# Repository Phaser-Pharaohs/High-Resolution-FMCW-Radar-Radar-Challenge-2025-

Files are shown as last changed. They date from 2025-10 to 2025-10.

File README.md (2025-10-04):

# Phaser Pharaohs – High-Resolution FMCW Radar (Radar Challenge 2025)

## Overview  
This repository contains the open-source project files from **Team Phaser Pharaohs** for the **IEEE AESS Radar Challenge 2025**.  
We modified the **Analog Devices CN0566 Phaser** platform to achieve **5 cm range resolution** for **non-destructive testing (NDT)**.  

---

## Motivation  
- provide a **non-destructive, high-resolution radar imaging tool**.  

---

## Key Achievements  
- Expanded usable radar **bandwidth from 500 MHz → 3 GHz**  
- Achieved **5 cm range resolution** and resolved **7 cm target separations**  
- Designed and fabricated custom **Horn TX** and **Vivaldi RX** antennas  
- Implemented **near-field focused beamforming** for sub-meter imaging  
- Demonstrated imaging on **sandbox rods** and **RAAC samples**  

---

## Hardware Modifications  
Full details are in [`docs/Modifications.docx`](docs/Modifications.docx).  
Summary of changes:  

- **Filters**  
  - Replaced *LFCW-1062+* with *LFCW-1142+* (TX/RX path)  
  - Removed *BFCN-1052+* on TX path  
  - Optional IF bandpass filter for SNR improvement  
- **Local Oscillator**: HMC735 VCO extended to **9.5–12.6 GHz**  
- **Antennas**  
  - **Vivaldi RX Array**  
    - Fabrication substrate: **Rogers RT/duroid 5880, 0.062” (1.575 mm)**  
    - Layout provided in **ODB++ format**  
  - **Horn TX Antennas** (12 dBi and 18 dBi)  
    - CAD models in **STL format**  
    - SMA connector: **MC002927**  
    - Inner pin length: **7 mm** inside waveguide (coax-to-waveguide transition)  
- **Routing**: RF rerouted to MMCX connectors for external antenna interfacing  

**Result:** Operation extended to **8–11 GHz** with ~5 cm resolution, optimized for high-resolution short-range imaging.  

---

## Repository Structure  
```
├── hardware/          
│   ├── horns/         # STL models for 12 dBi and 18 dBi horn antennas
│   ├── vivaldi/       # ODB++ files for Vivaldi PCB antenna
│   └── docs/          # Antenna datasheets and fabrication notes
├── software/          # Python/Matlab scripts for data acquisition & processing
├── experiments/       # Test datasets (sandbox rods, RAAC panels)
├── docs/              # Challenge documentation and presentations
│   ├── IEEE-Challenge-Flyer.pdf
│   ├── PhaserPharaohs_Presentation.pptx
│   └── Modifications.docx
└── README.md
```

---

## Installation & Usage  

### Requirements  
- CN0566 Phaser kit (modified)  
- ADALM-PLUTO SDR  
- Python ≥ 3.9 with:  
  ```
  numpy
  matplotlib
  scipy
  pyadi-iio
  ```

### Example Run  
```bash
git clone https://github.com/<your-org>/phaser-pharaohs-radar.git
cd phaser-pharaohs-radar/software

# Acquire test data
python acquire_data.py

# Process and plot results
python process_results.py
```

---

## Results  
- **Sandbox test**: resolved two rods at **7–10 cm separation**  
- **RAAC sample**: imaged hidden steel reinforcement with focused beamforming  
- Achieved **6× resolution improvement** over stock Phaser configuration  

---

## Future Work  
- 3D reconstruction using antenna array + translational motion  
- SAR/ISAR extensions for larger structures  
- Applications in **bridges, tunnels, and aerospace composites**  

---

## References  
- [Analog Devices CN0566 Phaser](https://www.analog.com/cn0566)  
- [IEEE AESS Radar Challenge 2025](https://ieee-aess.org/radar-challenge)  
- [RadarConf 2025 – Krakow](https://radarconf2025.org/)  

---

## License  
Released under the **MIT License** in accordance with the Radar Challenge open-source requirement.

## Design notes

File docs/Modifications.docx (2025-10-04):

Hardware Modifications

| No | PN | Description | Operating freq. | Notes
Tx path | 1 | AD9363 | RF Agile Transceiver | 325 MHz to 3.8 GHz
| 2 | LFCG-2500+ | Low Pass Filter | DC to 2500 MHz
| 3 | LTC5548 | Microwave Mixer | RF 2GHz to 14GHz IF DC–6GHz
| 4 | LFCW-1062+ | Low Pass Filter | DC to 10.6 GHz | Replace with LFCW-1142+
| 5 | BFCN-1052+ | LTCC Band Pass Filter | 9700 - 11950 MHz | Remove but Can be kept temporarily
| 6 | ADL8107 | Low Noise Amplifier | 6 GHz to 18 GHz
Rx path | 1 | ADL8107 | Low Noise Amplifier | 6 GHz to 18 GHz
| 2 | ADAR1000 | 4-Channel Beamformer | 8 GHz to 16 GHz
| 3 | LFCW-1062+ | Low Pass Filter | DC to 10.6 GHz | Replace with LFCW-1142+
| 4 | LTC5548 | Microwave Mixer | RF 2GHz to 14GHz IF DC–6GHz
| 5 | BFCN-1801+ | LTCC Band Pass Filter | 1400 - 2320 MHz
Local oscillator | 1 | ADF4159 | Frequency Synthesizer | 500MHz -13GHz
| 2 | HMC735 | VCO with Divide-by-4 | 10.5 - 12.2 GHz | 9.5-12.6
| 3 | HMC655 | 6 dB Passive Attenuator | DC - 50 GHz
| 4 | ADRF5019 | SPDT Switch, Nonreflective | 100 MHz to 13 GHz
| 5 | EP2C+ | 2 Ways MMIC DC Pass Power Splitter | 1800 - 12500 MHz
Antenna | 1 | | 8-element patch antenna | 10-10.5GHz | Replace with Vivaldi Array 8-11 GHz

*Tx: Replace (LFCW-1062+) with (LFCW-1142+) and remove (BFCN-1052+) then we can change the Tx frequency to be 6-14GHz.

*Rx: Replace (LFCW-1062+) with (LFCW-143+) then we can change the Rx frequency to be 8-14GHz.

*LO: The VCO operating frequency is 10.5 - 12.2 GHz, but according to the datasheet, this could be extended to be from 9.5- 12.6 GHz.

*Antenna: The patch antenna array has a limited bandwidth. We can replace it with wider bandwidth elements, such as Vivaldi. The routing should be modified to the mmcx connectors instead of the patch antennas.

After the modifications, the radar could operate between 8-11 GHz with a 1.5 GHz IF frequency, offering good range resolution. Applications that require high resolution.

To enhance the SNR, another BPF centred at the IF frequency could be added between the radar board (CN0566) and the ADALM-PLUTO SDR.

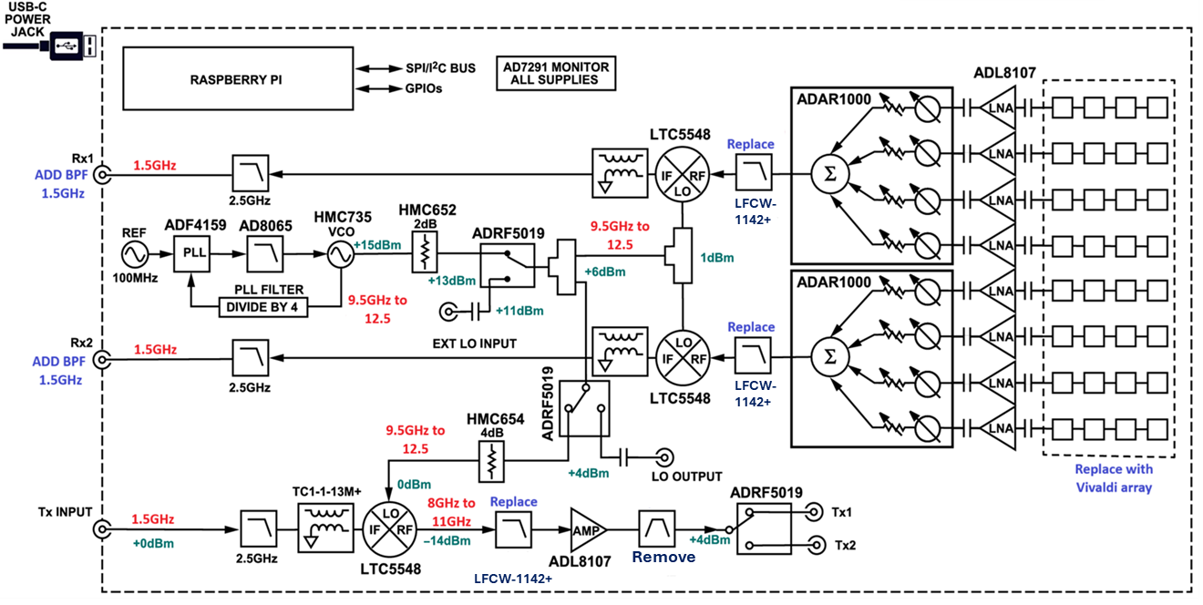
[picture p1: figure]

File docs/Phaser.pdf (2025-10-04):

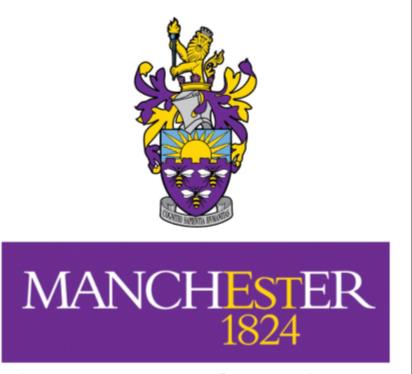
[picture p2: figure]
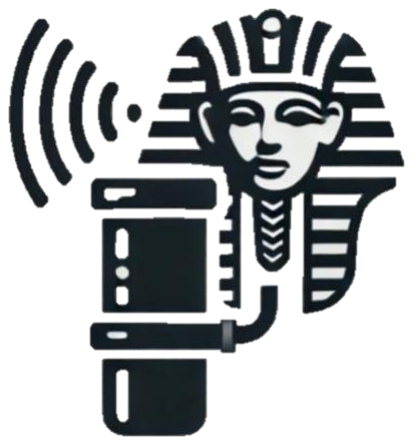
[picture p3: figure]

# IEEE AESS Radar Challenge

2025

# Phaser Pharaohs team

# High-Resolution FMCW Radar for Non-Destructive Testing of RAAC Structures

IEEE AESS Radar Challenge 2025 | Phaser Pharaohs | 6 Oct 2025

Kamal Khalil, Samuel Forester, Frank Podd, Tony Peyton

# Project Overview

## Objective:

Modify the Analog Devices CN0566 Phaser radar platform and use it for the non-destructive Testing (NDT) of Reinforced Autoclaved Aerated Concrete (RAAC) panels.

## Motivation:

- RAAC is porous, absorbs moisture, and leads to steel rebar corrosion.

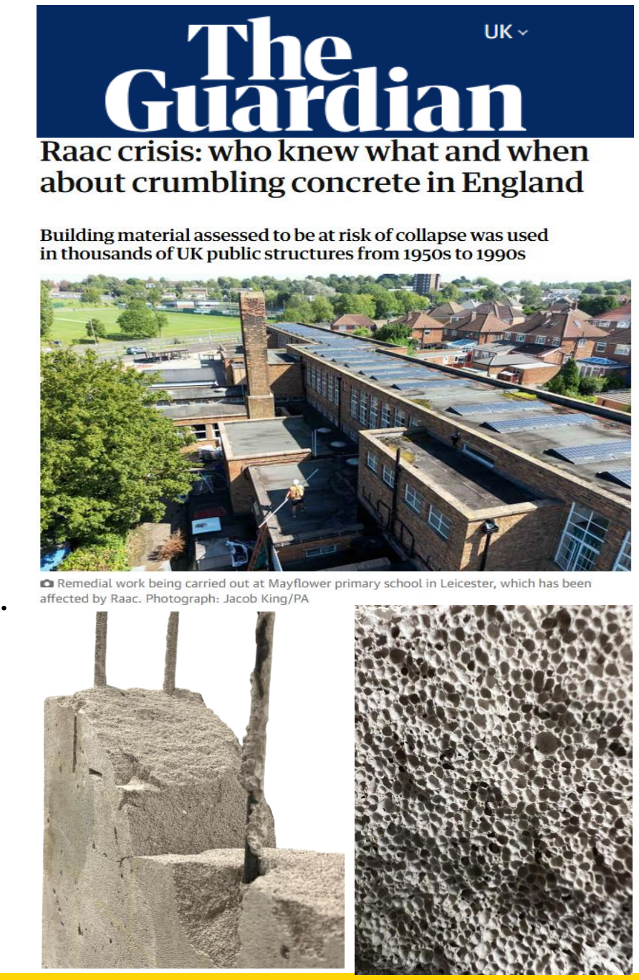
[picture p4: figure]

- Its short lifespan (~30 years) and hidden failure modes pose safety risks.
- Current inspection methods are limited or destructive.

## Project Goal:

Leverage beamforming + bandwidth expansion to:
- Achieve 5 cm range resolution and fine angular resolution
- Build a prototype system for RAAC imaging at short range (<1 m)

# Proposed Modifications

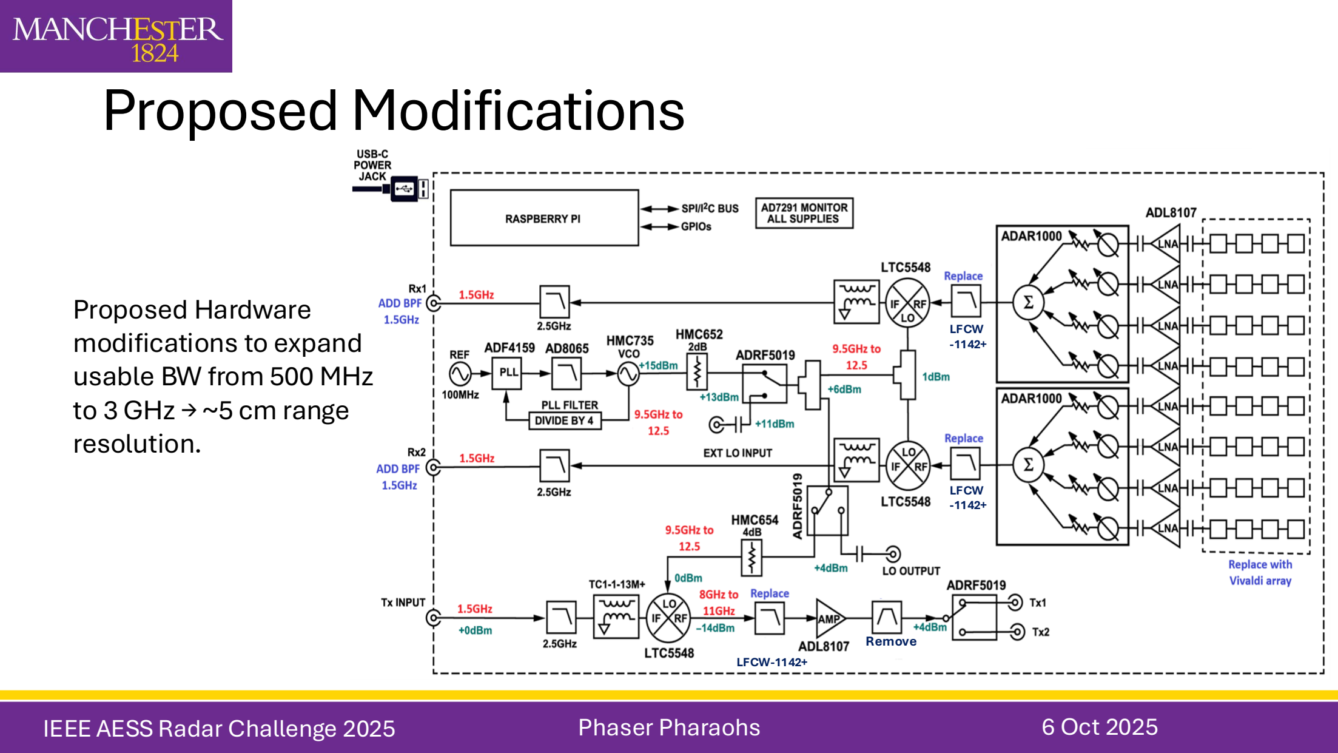
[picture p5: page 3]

LFCW-1142+

LFCW
-1142+

LFCW
-1142+

Remove

Proposed Hardware
modifications to expand
usable BW from 500 MHz
to 3 GHz → ~5 cm range
resolution.

# Hardware Modifications

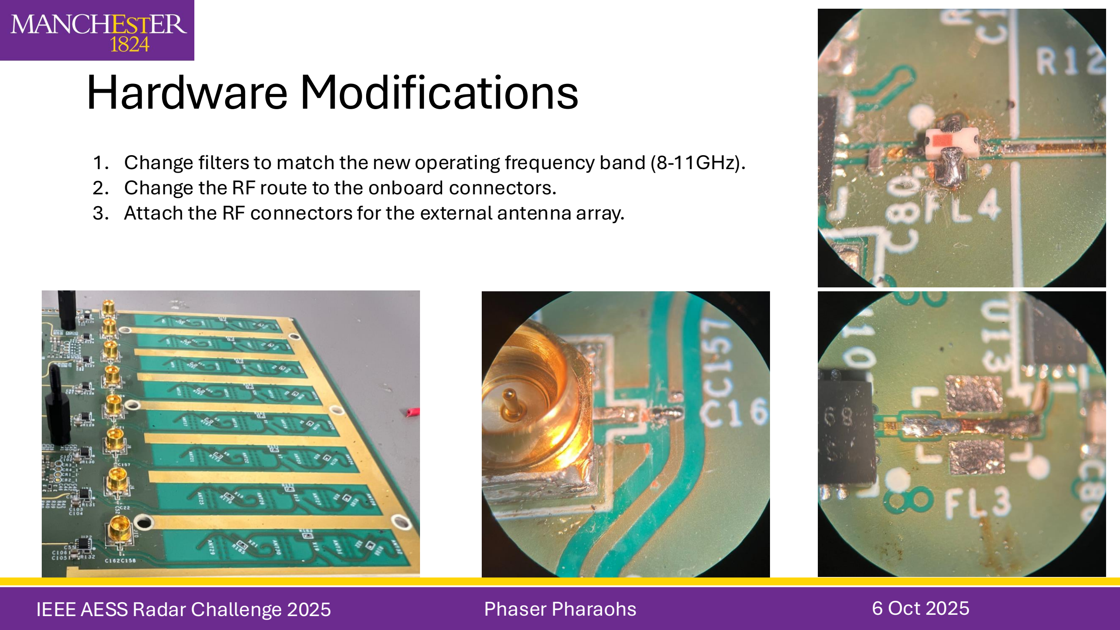
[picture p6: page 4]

1. Change filters to match the new operating frequency band (8-11GHz).
2. Change the RF route to the onboard connectors.
3. Attach the RF connectors for the external antenna array.

# Receiving Antenna Array

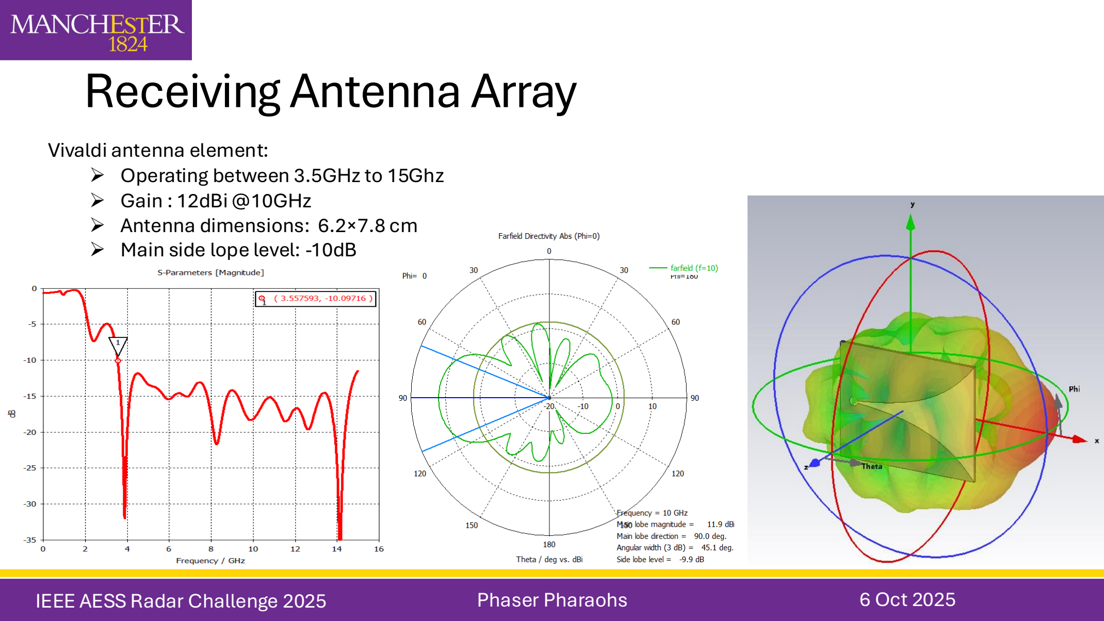
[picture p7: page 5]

Vivaldi antenna element:
- Operating between 3.5GHz to 15Ghz
- Gain : 12dBi @10GHz
- Antenna dimensions: 6.2×7.8 cm
- Main side lope level: -10dB

# Transmitting Horn Antenna

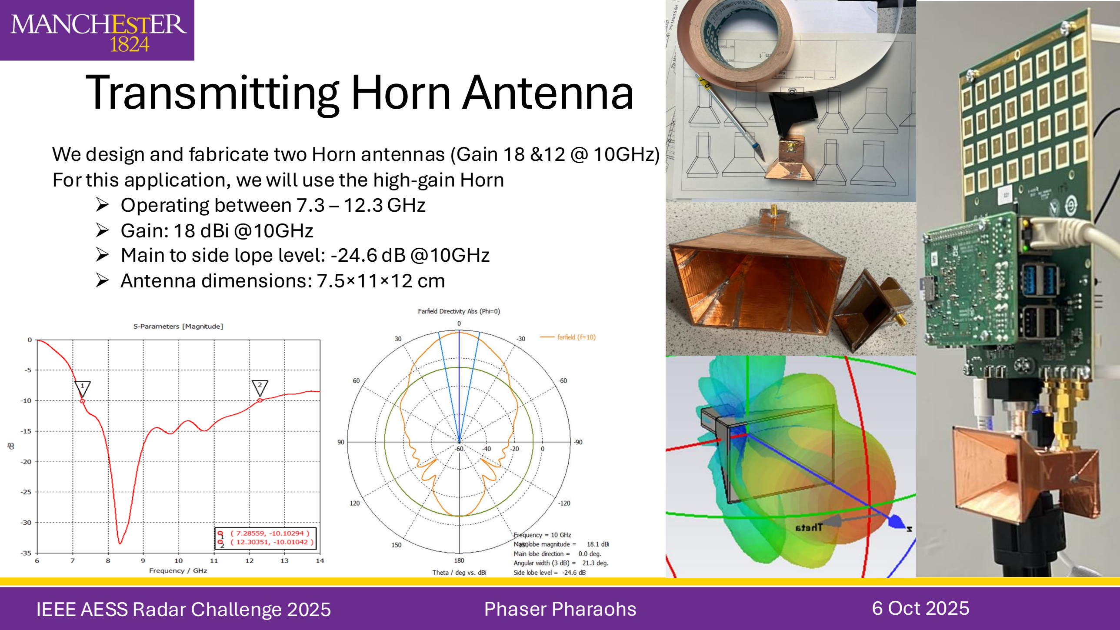
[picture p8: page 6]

We design and fabricate two Horn antennas (Gain 18 &12 @ 10GHz) For this application, we will use the high-gain Horn
- Operating between 7.3 – 12.3 GHz
- Gain: 18 dBi @10GHz
- Main to side lope level: -24.6 dB @10GHz
- Antenna dimensions: 7.5×11×12 cm

# Standard Configuration

## Tapered beam steering / BW 500 MHz

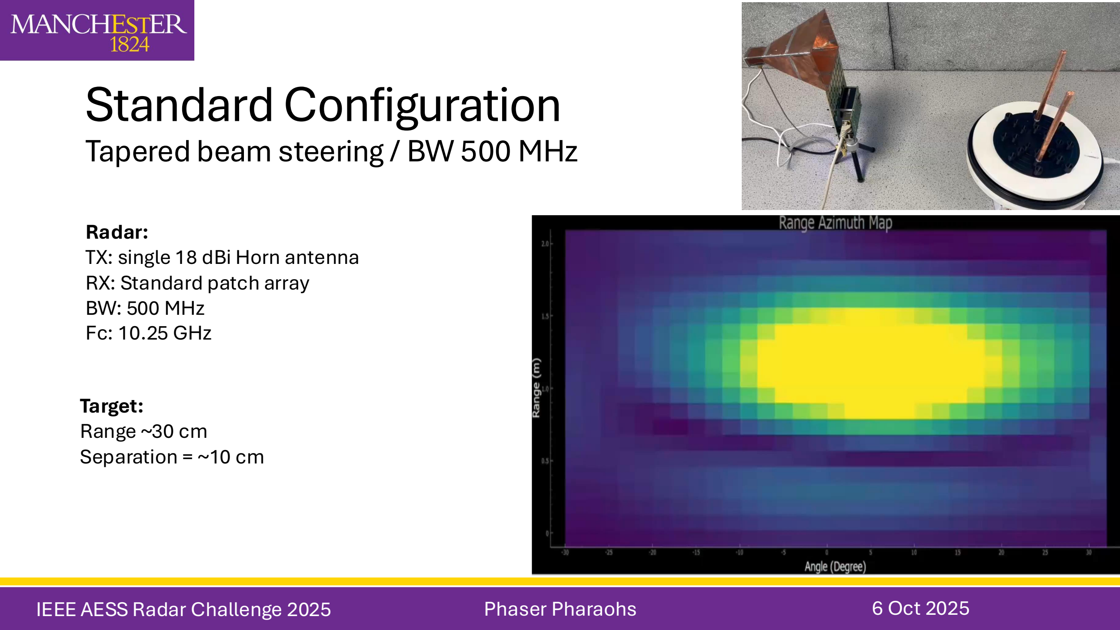
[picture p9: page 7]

Target:
Range ~30 cm
Separation = ~10 cm

Radar:
TX: single 18 dBi Horn antenna RX: Standard patch array
BW: 500 MHz
Fc: 10.25 GHz

# High Range Resolution Configuration

## Tapered beam steering / BW 3000 MHz

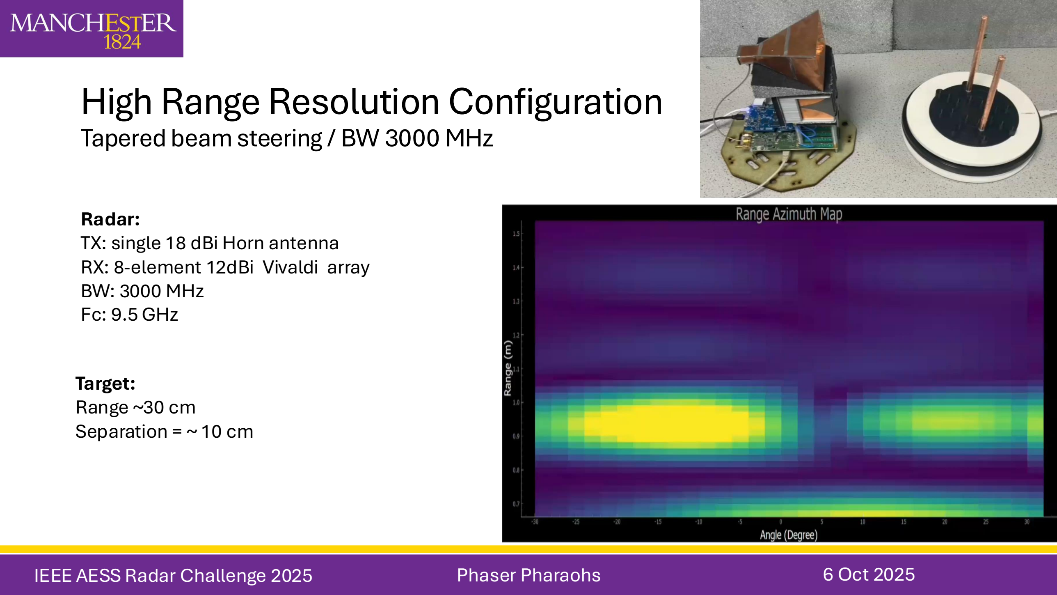
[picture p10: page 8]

Target:
Range ~30 cm
Separation = ~ 10 cm

Radar:
TX: single 18 dBi Horn antenna RX: 8-element 12dBi Vivaldi array BW: 3000 MHz
Fc: 9.5 GHz

# Plane-wave beam steering vs Focused beam steering

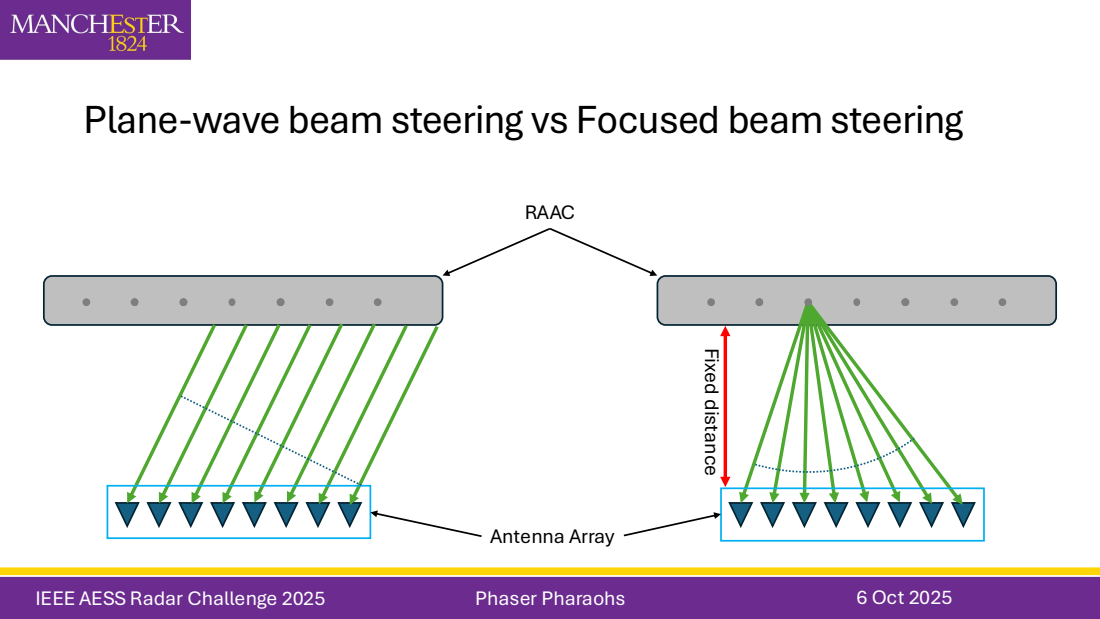
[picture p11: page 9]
RAAC; Antenna Array; Fixed distance

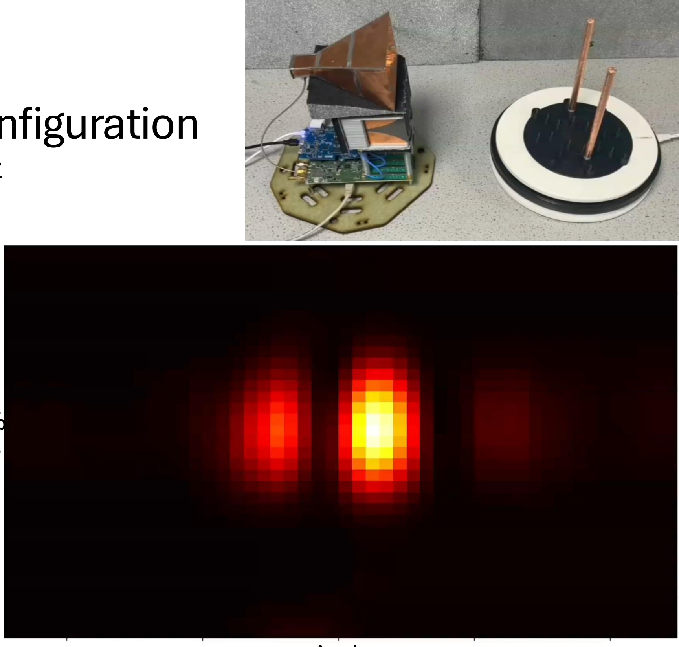
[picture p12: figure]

# High Range Resolution Configuration

## Focused beam steering / BW 3000 MHz

Target:
Range ~30 cm
Separation = ~ 10 cm

Radar:
TX: single 18 dBi Horn antenna RX: 8-element 12dBi Vivaldi array BW: 3000 MHz
Fc: 9.5 GHz

Angle

Range

# Inspecting a Sandbox with Two Metal Rods

## Tapered beam steering / BW 500 MHz

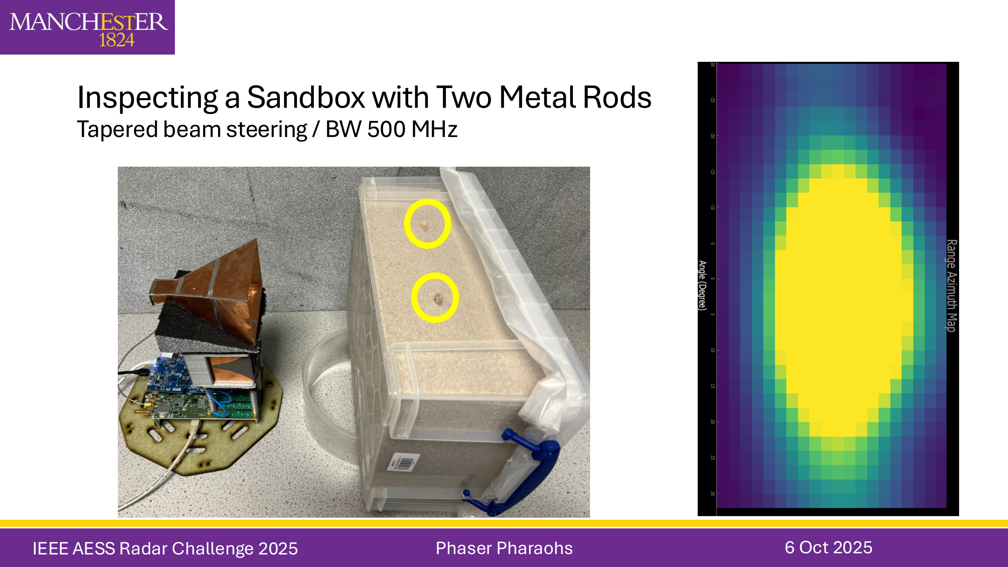
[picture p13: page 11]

# Inspecting a Sandbox with Two Metal Rods

## Focused beam steering / BW 3000 MHz

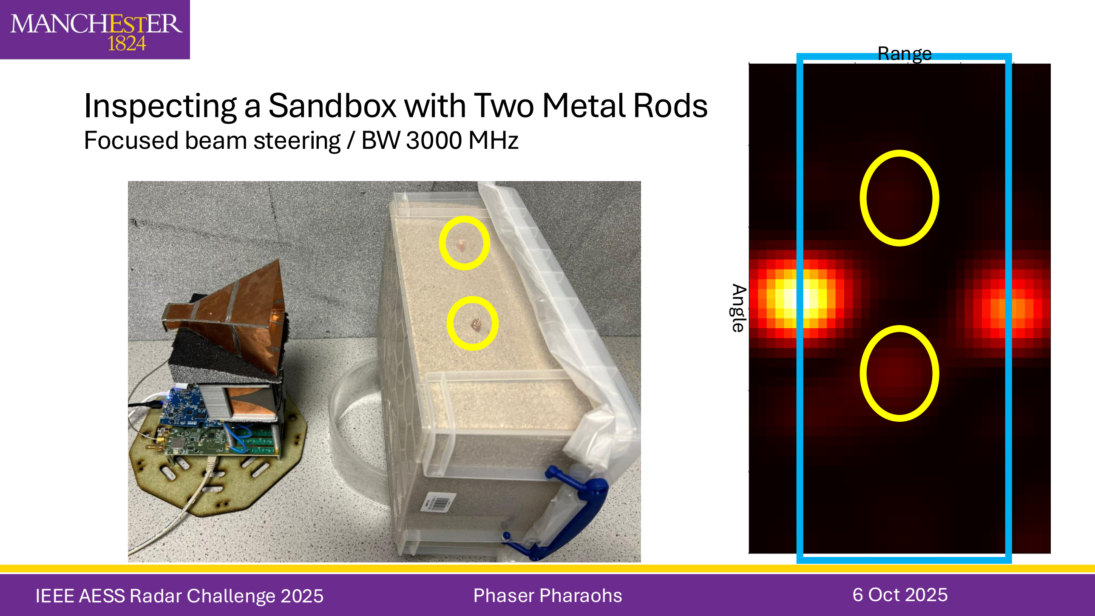
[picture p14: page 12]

IEEE AESS Radar Challenge 2025 | Phaser Pharaohs | 6 Oct 2025 Angle

Range

# Inspecting a Sandbox with Two Metal Rods

## Focused beam steering / BW 3000 MHz

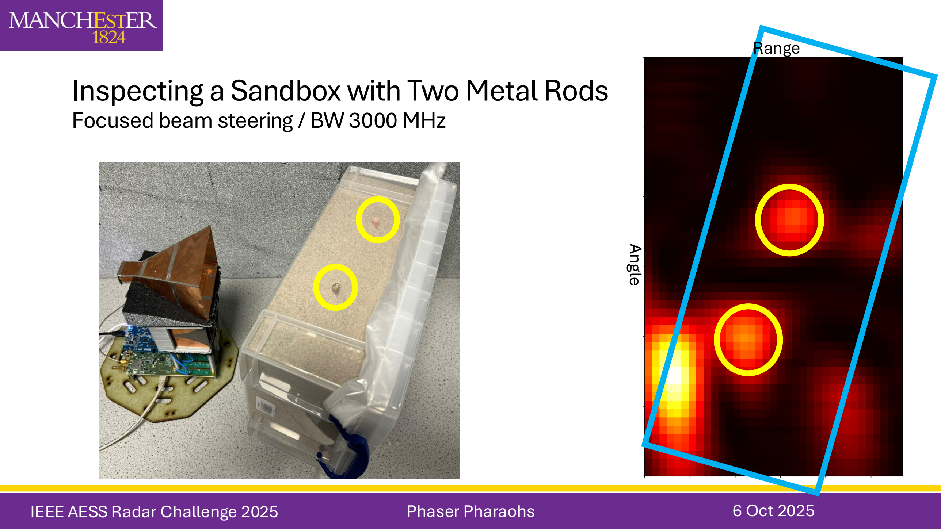
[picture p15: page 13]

IEEE AESS Radar Challenge 2025 | Phaser Pharaohs | 6 Oct 2025 Angle

Range

# Inspecting Steel Reinforcement of a RAAC Sample

## Focused beam steering / BW 3000 MHz

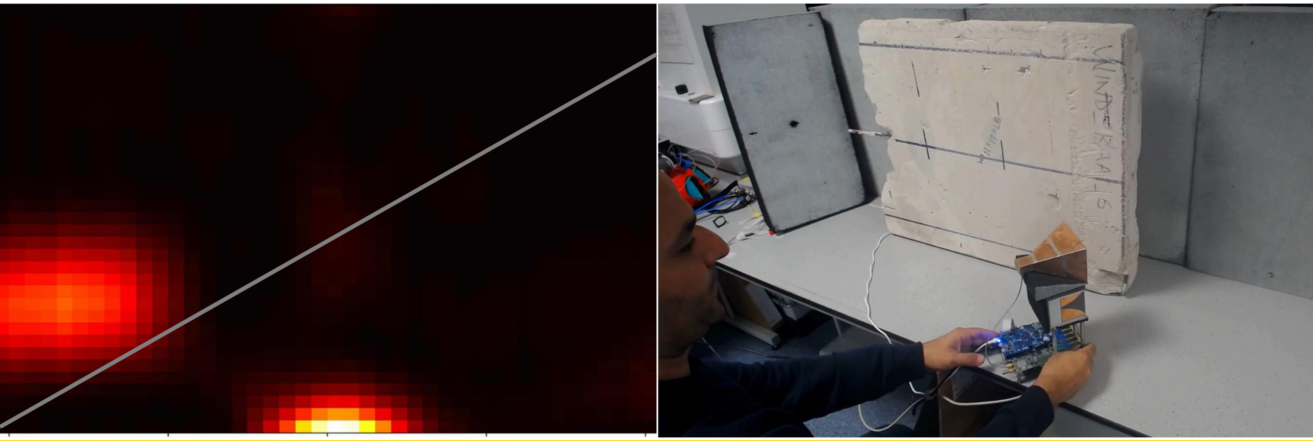
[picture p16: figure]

# Conclusion and Future work

You could add something on combining the array with SAR
conclusion that the Phasor platform could be ideal for a host of new, very short-range radar applications in NDT

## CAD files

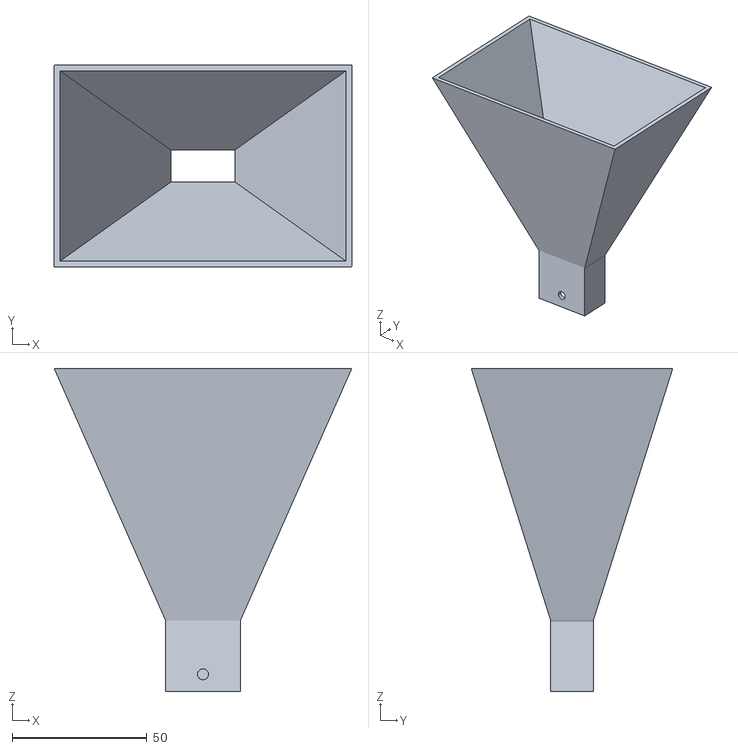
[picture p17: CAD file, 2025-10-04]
hardware/horns/X_Horn_18dB_Gain.stl
110.6 x 74.9 x 120.1

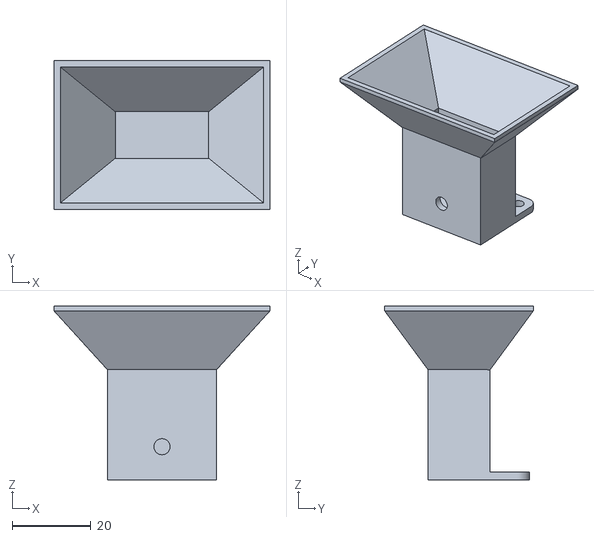
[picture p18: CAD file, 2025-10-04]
hardware/horns/X_Horn_12dB_Gain.stl
54.8 x 37.7 x 44.1

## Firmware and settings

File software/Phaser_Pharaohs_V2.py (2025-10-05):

# %%
# Copyright (C) 2024 Analog Devices, Inc.
#
# All rights reserved.
#
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
# IN NO EVENT SHALL ANALOG DEVICES BE LIABLE FOR ANY DIRECT, INDIRECT, INCIDENTAL, SPECIAL,
# EXEMPLARY, OR CONSEQUENTIAL DAMAGES (INCLUDING, BUT NOT LIMITED TO, INTELLECTUAL PROPERTY
# RIGHTS, PROCUREMENT OF SUBSTITUTE GOODS OR SERVICES; LOSS OF USE, DATA, OR PROFITS; OR
# BUSINESS INTERRUPTION) HOWEVER CAUSED AND ON ANY THEORY OF LIABILITY, WHETHER IN CONTRACT,
# STRICT LIABILITY, OR TORT (INCLUDING NEGLIGENCE OR OTHERWISE) ARISING IN ANY WAY OUT OF
# THE USE OF THIS SOFTWARE, EVEN IF ADVISED OF THE POSSIBILITY OF SUCH DAMAGE.

'''FMCW Range Doppler Demo with Phaser (CN0566)
   Updated for new TDD engine (rev 0.39 Pluto firmware)
   Added pulse canceller MTI filter
   Jon Kraft, Sept 25 2024'''

# %%
# Imports
import sys
import time
import matplotlib
import matplotlib.pyplot as plt
import numpy as np
from scipy.signal import windows
import matplotlib.animation as animation
import time

plt.ion()


def pulse_canceller(data, num_chirps):
    diff = np.zeros((data.shape), dtype=np.complex_)
    for chirp in range(num_chirps - 1):
        chirp1 = data[chirp]
        chirp2 = data[chirp + 1]
        # phase = np.mean(np.angle(chirp2*np.conj(chirp1)))

        # phase = np.angle(np.correlate(chirp1,chirp2,mode='valid'))
        # diff[chirp] =  chirp1 - chirp2*np.exp(-1j*phase)

        diff[chirp] = chirp1 - chirp2
    return diff


def check_adc_saturation(data, bits=12):
    max_val = 2 ** (bits)
    min_val = -2 ** (bits)
    real_sat = np.any((data.real >= max_val) | (data.real <= min_val))
    imag_sat = np.any((data.imag >= max_val) | (data.imag <= min_val))
    return real_sat, imag_sat


def fft2D(data):
    doppler_win = windows.tukey(data.shape[0], alpha=0.3)  # or np.hanning(...)
    range_win = windows.tukey(data.shape[1], alpha=0.3)
    win_2d = np.outer(doppler_win, range_win)
    n_points, m_points = N * num_chirps, M * num_samples
    return np.fft.fftshift(np.fft.fft2(win_2d * data, s=(n_points, m_points))).T


# def AGC(data):
#    check_adc_saturation(data, bits=12)

plt.close('all')

'''This script uses the new Pluto TDD engine
   As of March 2024, this is in the main branch of https://urldefense.com/v3/__https://github.com/analogdevicesinc/pyadi-iio__;!!PDiH4ENfjr2_Jw!Bb5lEb30XAtzrjXeqE7eilGWUukYuPt3qljdVltpF1cFoY6vqc6erFNdShaeqKe_fsHWEYijonGPUu0icuHY$ [github[.]com]
   Also, make sure your Pluto firmware is updated to rev 0.39 (or later)
'''
import adi

print(adi.__version__)

# 4e6,8e9,3e9,900us,300steps

'''Key Parameters'''
sample_rate = 4e6  # 4e6
center_freq = 1.5e9
signal_freq = 100e3
rx_gain = 0  # must be between -3 and 70
tx_gain = 0  # must be between 0 and -88
output_freq = 8e9
chirp_BW = 3e9
ramp_time = 600  # us
num_chirps = 1
N_steps = ramp_time  # 400#int((ramp_time/1e6)*sample_rate)#300
max_range = 120
inespection_range = 0.3
min_scale = 0
max_scale = 100
plot_data = False
mti_filter = True
save_data = False
# saves data for later processing (use "Range_Doppler_Processing.py")
f = "big_drone_down_back_0dB_tx_gain.npy"

# %%
""" Program the basic hardware settings
"""
# Instantiate all the Devices
rpi_ip = "ip:phaser.local"  # IP address of the Raspberry Pi
sdr_ip = "ip:192.168.2.1"  # "192.168.2.1, or pluto.local"  # IP address of the Transceiver Block
# sdr_ip = "ip:phaser.local:50901"  # using IIO context port forwarding
my_sdr = adi.ad9361(uri=sdr_ip)
my_phaser = adi.CN0566(uri=rpi_ip, sdr=my_sdr)

# Initialize both ADAR1000s, set gains to max, and all phases to 0
my_phaser.configure(device_mode="rx")
my_phaser.element_spacing = 0.014
my_phaser.load_gain_cal()
my_phaser.load_phase_cal()
for i in range(0, 8):
    my_phaser.set_chan_phase(i, 0)

gain_list = [127] * 8
# gain_list = [8, 34, 84, 127, 127, 84, 34, 8]  # Blackman taper
for i in range(0, len(gain_list)):
    my_phaser.set_chan_gain(i, gain_list[i], apply_cal=True)

# Setup Raspberry Pi GPIO states
my_phaser._gpios.gpio_tx_sw = 0  # 0 = TX_OUT_2, 1 = TX_OUT_1
my_phaser._gpios.gpio_vctrl_1 = 1  # 1=Use onboard PLL/LO source  (0=disable PLL and VCO, and set switch to use external LO input)
my_phaser._gpios.gpio_vctrl_2 = 1  # 1=Send LO to transmit circuitry  (0=disable Tx path, and send LO to LO_OUT)

# Configure SDR Rx
my_sdr.sample_rate = int(sample_rate)
my_sdr.rx_lo = int(center_freq)
my_sdr.rx_enabled_channels = [0, 1]  # enable Rx1 and Rx2
my_sdr.gain_control_mode_chan0 = 'manual'  # manual or slow_attack
my_sdr.gain_control_mode_chan1 = 'manual'  # manual or slow_attack
my_sdr.rx_hardwaregain_chan0 = int(rx_gain)  # must be between -3 and 70
my_sdr.rx_hardwaregain_chan1 = int(rx_gain)  # must be between -3 and 70

# Configure SDR Tx
my_sdr.tx_lo = int(center_freq)
my_sdr.tx_enabled_channels = [0, 1]
my_sdr.tx_cyclic_buffer = True  # must set cyclic buffer to true for the tdd burst mode
my_sdr.tx_hardwaregain_chan0 = -88  # must be between 0 and -88
my_sdr.tx_hardwaregain_chan1 = int(tx_gain)  # must be between 0 and -88

# Configure the ADF4159 Ramping PLL
vco_freq = int(np.round(output_freq + signal_freq + center_freq))
BW = chirp_BW
num_steps = N_steps  # int(np.round(ramp_time))    # in general it works best if there is 1 step per us
my_phaser.frequency = int(np.round(vco_freq / 4))

my_phaser.freq_dev_range = int(np.round(BW / 4))  # total freq deviation of the complete freq ramp in Hz
my_phaser.freq_dev_step = int(np.round((BW / 4) / num_steps))  # This is fDEV, in Hz.  Can be positive or negative
my_phaser.freq_dev_time = int(np.round(ramp_time))  # total time (in us) of the complete frequency ramp
print("requested freq dev time (us) = ", ramp_time)
my_phaser.delay_word = 4095  # 12 bit delay word.  4095*PFD = 40.95 us.  For sawtooth ramps, this is also the length of the Ramp_complete signal
my_phaser.delay_clk = "PFD"  # can be 'PFD' or 'PFD*CLK1'
my_phaser.delay_start_en = 0  # delay start
my_phaser.ramp_delay_en = 0  # delay between ramps.
my_phaser.trig_delay_en = 0  # triangle delay
my_phaser.ramp_mode = "single_sawtooth_burst"  # ramp_mode can be:  "disabled", "continuous_sawtooth", "continuous_triangular", "single_sawtooth_burst", "single_ramp_burst"
my_phaser.sing_ful_tri = 0  # full triangle enable/disable -- this is used with the single_ramp_burst mode
my_phaser.tx_trig_en = 1  # start a ramp with TXdata
my_phaser.enable = 0  # 0 = PLL enable.  Write this last to update all the registers

# %%
""" Synchronize chirps to the start of each Pluto receive buffer
"""
# Configure TDD controller
sdr_pins = adi.one_bit_adc_dac(sdr_ip)
sdr_pins.gpio_tdd_ext_sync = True  # If set to True, this enables external capture triggering using the L24N GPIO on the Pluto.  When set to false, an internal trigger pulse will be generated every second
tdd = adi.tddn(sdr_ip)
sdr_pins.gpio_phaser_enable = True
tdd.enable = False  # disable TDD to configure the registers
tdd.sync_external = True
tdd.startup_delay_ms = 0
PRI_ms = ramp_time / 1e3 + 0.35
tdd.frame_length_ms = PRI_ms  # each chirp is spaced this far apart
# tdd.frame_length_raw = PRI_ms/1000 * 2 * sample_rate
tdd.burst_count = num_chirps  # number of chirps in one continuous receive buffer

tdd.channel[0].enable = True
tdd.channel[0].polarity = False
tdd.channel[0].on_raw = 0
tdd.channel[0].off_raw = 10
tdd.channel[1].enable = True
tdd.channel[1].polarity = False
tdd.channel[1].on_raw = 0
tdd.channel[1].off_raw = 10
tdd.channel[2].enable = True
tdd.channel[2].polarity = False
tdd.channel[2].on_raw = 0
tdd.channel[2].off_raw = 10
tdd.enable = True

# From start of each ramp, how many "good" points do we want?
# For best freq linearity, stay away from the start of the ramps
ramp_time = int(my_phaser.freq_dev_time)  # - begin_offset_time)
ramp_time_s = ramp_time / 1e6
begin_offset_time = 0 * ramp_time_s  # time in seconds
print("actual freq dev time = ", ramp_time)
good_ramp_samples = int(np.round((ramp_time_s - begin_offset_time) * sample_rate))
start_offset_time = tdd.channel[0].on_ms / 1e3 + begin_offset_time
start_offset_samples = int(np.round(start_offset_time * sample_rate))

# Pluto receive buffer size needs to be greater than total time for all chirps
total_time = tdd.frame_length_ms * num_chirps  # time in ms
print("Total Time for all Chirps:  ", total_time, "ms")
buffer_time = 0
power = 12
while total_time > buffer_time:
    power = power + 1
    buffer_size = int(2 ** power)
    buffer_time = buffer_size / sample_rate * 1000  # buffer time in ms
    if power == 23:
        break  # max pluto buffer size is 2**23, but for tdd burst mode, set to 2**22
print("buffer_size:", buffer_size)
my_sdr.rx_buffer_size = buffer_size
print("buffer_time:", buffer_time, " ms")

# %%
""" Calculate ramp parameters
"""
PRI_s = PRI_ms / 1e3
PRF = 1 / PRI_s
num_bursts = tdd.burst_count

# Split into frames
N_frame = int(np.round(PRI_s * float(sample_rate)))

# Obtain range-FFT x-axis
c = 299792458
wavelength = c / output_freq
slope = BW / ramp_time_s
freq = np.linspace(-sample_rate / 2, sample_rate / 2, N_frame)
dist = (freq - signal_freq) * c / (2 * slope)

# Resolutions
R_res = c / (2 * BW)
v_res = wavelength / (2 * num_bursts * PRI_s)

# Doppler spectrum limits
max_doppler_freq = PRF / 2
max_doppler_vel = max_doppler_freq * wavelength / 2

# %%
""" Create a sinewave waveform for Pluto's transmitter
"""
# Create a sinewave waveform
N = int(2 ** 18)
fc = int(signal_freq)
ts = 1 / float(sample_rate)
t = np.arange(N) * ts
iq = np.exp(1j * 2 * np.pi * fc * t)  # complex sinewave at +fc
iq = (iq * 2 ** 14).astype(np.complex64)

# transmit data from Pluto
my_sdr.tx([iq, iq])

# %%
# Function to collect data
i = 0
cmn = ''


def get_radar_data():
    global range_doppler, sum_data
    # Collect data
    my_phaser._gpios.gpio_burst = 0
    my_phaser._gpios.gpio_burst = 1
    my_phaser._gpios.gpio_burst = 0
    data = my_sdr.rx()
    chan1 = data[0]
    chan2 = data[1]
    sum_data = chan1 + chan2

    # Process data
    # Make a 2D array of the chirps for each burst
    rx_bursts = np.zeros((num_bursts, good_ramp_samples), dtype=complex)
    for burst in range(num_bursts):
        start_index = start_offset_samples + burst * N_frame
        stop_index = start_index + good_ramp_samples
        rx_bursts[burst] = sum_data[start_index:stop_index]
    return rx_bursts


def freq_process(data):
    doppler_win = windows.tukey(data.shape[0], alpha=1)  # or np.hanning(...)
    range_win = windows.tukey(data.shape[1], alpha=1)
    win_2d = np.outer(doppler_win, range_win)

    rx_bursts_fft = np.fft.fftshift(abs(np.fft.fft2(data * win_2d)))
    # rx_bursts_fft = abs(np.fft.fft(rx_bursts*range_win,axis=1))
    range_doppler_data = np.log10(rx_bursts_fft).T
    # range_doppler_data = np.clip(range_doppler_data, min_scale, max_scale)  # clip the data to control the max spectrogram scale
    return range_doppler_data


# Give the device a moment to initialize
time.sleep(0.05)  # half a second
# OR do a dummy read
try:
    rx_bursts = get_radar_data()
except OSError:
    pass  # expected on first call
rx_bursts = get_radar_data()

# alpha=0.1
# ema=0
# while True:
#    data = get_radar_data()
#    plt.clf()
#    plt.plot(np.real((data.T)))
#    # fft = abs(np.fft.fft(data,axis=1).T)
#    # ema = alpha * ema + (1 - alpha) * fft
#    # plt.plot(abs(fft)[:300])# - ema))
#    plt.pause(0.1)
# sys.exit()

BW = chirp_BW
T = ramp_time * 1e-6
c = 299792458
fs = sample_rate
t = np.arange(good_ramp_samples) / fs
freqs = np.fft.fftfreq(good_ramp_samples, d=1 / fs)

# imaging voxels
nx, nz = 64, 64
z = np.linspace(0.05, 1, nz)
x = np.linspace(-1, 1, nx)
X, Z = np.meshgrid(x, z, indexing='ij')
X, Z = X.flatten(), Z.flatten()

rx_coordinates = 13
rxx = np.linspace(-0.3, 0.3, rx_coordinates)
rxz = np.linspace(0, 0, rx_coordinates)

image_shape = (nx, nz)
image = np.zeros((image_shape[0], image_shape[1]), dtype=np.complex128).flatten()

nx = 50
k = 2 * np.pi / wavelength
z = inespection_range
x = np.linspace(-0.5, 0.5, nx)
fs = sample_rate

spacing = 0.014
N_elements = 8
half_span = spacing * (N_elements - 1) / 2  # total extent to cover 8 points
rxx = np.linspace(-half_span, half_span, N_elements)
rxz = np.linspace(0, 0, 8)
r = np.sqrt((rxx[:, None] - x) ** 2 + (rxz[:, None] - z) ** 2)

phase = np.exp(1j * k * r)
angles = np.degrees(np.angle(phase))

f_beat = signal_freq
f_offset = 22.67e3
t = np.arange(good_ramp_samples) / fs
offset = np.exp(-1j * 2 * np.pi * (f_beat + f_offset) * t)


zero_pad_factor=5
fft_size = good_ramp_samples * zero_pad_factor

while True:
    image = np.zeros((nx, fft_size), dtype=np.complex128)
    for i in range(0, nx):
        for k in range(0, 8):
            my_phaser.set_chan_phase(k, angles[k, i])
        data = get_radar_data()[0]

        # Apply window function
        windowed_data = data * offset* np.hanning(len(data))

        # Perform FFT with zero-padding using the n parameter
        image[i] = np.fft.fft(windowed_data, n=fft_size)

    # Calculate range resolution
    range_resolution = c / (2 * BW)  # Theoretical range resolution
    max_display_range = range_resolution * fft_size / 2

    extent = [np.min(x), np.max(x), 0, max_display_range]
    plt.clf()

    # Display up to Nyquist frequency
    plt.imshow(np.abs(image)[:, :7*zero_pad_factor].T ** 2,
               extent=extent,
               origin='lower',
               aspect='auto',
               cmap='hot')
    plt.colorbar(label='Intensity')
    plt.xlabel('Angle')
    plt.ylabel('Range (m)')
    plt.title(f'Zero-padded Range Profile ({zero_pad_factor}x resolution)')
    plt.pause(0.1)
